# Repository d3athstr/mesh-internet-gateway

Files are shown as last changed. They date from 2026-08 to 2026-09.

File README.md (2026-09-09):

# Mesh Internet Gateway (`meshgw`)

Wired-Ethernet Raspberry Pi + 1 W SX1262 LoRa gateway running **`meshtasticd`**.
Bridges the Empire12 / Techtaria LoRa mesh to the internet over MQTT, and
publishes **E12-owned nodes only** to the public Meshtastic map directories.

PartsBin project **[18]**. Status: **DEPLOYED AND LIVE 2026-09-09.** The HAT is
populated, the Pi is wired and provisioned, and the node is on the mesh with the
MQTT bridge connected.

**The E22 land pattern is VERIFIED.** `meshtasticd` reported `sx1262 init
success` on first start with the module soldered to a rev A board — so the
boards fabbed on the recorded `GEOMETRY_OVERRIDE` are good, and that override is
now cleared in `fab_gate.py`.

**Projected cost ~$81.81**, of which **$35.00 is the Raspberry Pi itself** —
check the shelf first, a spare 3B/3B+/4 makes that line $0. The next largest
is the E22 at **$17.10**, which is what was actually paid on a single-item
AliExpress order; LCSC lists the bare module at ~$7.19, so the difference is
probably bundled shipping and worth checking before buying a second one. The
custom HAT is ~$0.80 ($4 for 5 boards) and the printed enclosure ~$1.20 of
filament — between them under 3 % of the build.

---

## Why this exists

Today the mesh's only internet-adjacent node is the Heltec V4 gateway
`!f66ae684`, a WiFi-attached node on the IoT VLAN. It is a poor
foundation for an internet bridge:

| Problem | Evidence |
|---|---|
| ESP32 **WiFi-hang** — CPU alive, WiFi stack dead, every TCP client drops | Down again **2026-08-10 ~12:37**, ops bridge crash-looping `No route to host` → `BrokenPipe`. Needs a Tuya-switch power cycle to recover. |
| Serves **one** streaming TCP-API client, reliably | Already forced HA onto its own dedicated V3 radio (**D049**) |
| Bridge does **not** auto-reconnect | `meshtastic-bridge-watchdog.timer` exists solely to paper over it |
| WiFi-only | No wired path; it lives on E12-DMZ WiFi |

That radio is on the **load-bearing OOB control path** (4th reach channel,
D048). Hanging an internet/MQTT bridge off it stacks a new dependency on the
component that is already the mesh's most frequent outage.

`meshgw` is a separate, wired, purpose-built box. The V4 keeps doing C&C;
`meshgw` owns the internet bridge.

---

## Design

| Piece | Choice | Why |
|---|---|---|
| Host | **Raspberry Pi 3B/3B+** (wired Ethernet) | Native Ethernet kills the WiFi-hang failure mode. `meshtasticd` is a real Linux daemon — multiple concurrent API clients, no single-TCP-slot contention. Cheapest board with Ethernet + 40-pin header; a spare is likely already on the shelf. |
| Radio | **Ebyte E22-900M30S** (SX1262 + PA, 30 dBm) | ~$14 bare module vs ~$30 for a commercial LoRa HAT, and **1 W / 30 dBm** vs the Heltec's 22 dBm SX1262 ceiling — ~8 dB more link budget on the same mesh. |
| Carrier | **Custom HAT PCB** (`hardware/meshgw-hat/`) | A bare module needs a carrier. KiCad 9 headless, `gen.py` + freerouting — same workflow as the OSL / FD2 / Warden carriers. |
| Enclosure | **3D-printed, parametric** (`enclosure/`) | OpenSCAD source. Indoor shelf/rack box — *not* weatherproof. |
| Uplink | MQTT → `mqtt.meshtastic.org` | What makes nodes appear on the public map directories. |

### Ruled out: ESP32 + Ethernet

WT32-ETH01 (ESP32 + LAN8720) would have been the cheapest wired option
(~$8). **Rejected:** native ESP32 Ethernet support is
[meshtastic/firmware PR #9586](https://github.com/meshtastic/firmware/pull/9586),
which is **closed and never merged** (verified 2026-08-10 via the GitHub API).
Using it means maintaining a firmware fork on the OOB control path. Not
acceptable for this role.

### Ruled out: reuse an in-stock Heltec V4

Zero cost (2 on hand), but it reintroduces the exact WiFi-hang failure mode
that has the current gateway down as this is being written. Reasonable as a
**cold standby**, not as the primary.

---

## Privacy boundary — read `docs/privacy-boundary.md`

This is the part that must not be got wrong.

- **Only E12-owned nodes** are published: `meshgw` itself, the Heltec V4
  gateway, the HA V3, and the e12solar RAK router.
- **Techtaria customer-home endpoints stay dark.** No `ok_to_mqtt`, no map
  reporting, ever. Publishing them would put approximate customer home
  locations on public maps.
- **`paw-cmd` (idx 1, C&C) and `Techtaria` (idx 2, community) have uplink AND
  downlink OFF.** Only the default primary channel uplinks. Downlink on the
  C&C channel would let internet-sourced packets inject into the command path.

The HMAC envelope on the C&C receiver is a second line of defence, not a
reason to relax the first.

---

## Repo layout

```
config/meshtasticd/    config.yaml (E22 pinout), MQTT + channel policy, systemd
hardware/meshgw-hat/   KiCad: netlist.py, gen.py, gen_pcb.py, route.sh,
                       check_geometry.py, lib.pretty/
enclosure/             OpenSCAD parametric case + build notes
docs/                  design notes, privacy boundary, provisioning runbook
scripts/               provisioning helpers
```

`netlist.py` is the **single source of truth for the pinout** — the schematic
generator, the board generator and (by hand) `config/meshtasticd/config.yaml`
all derive from it. It used to be duplicated in `gen.py` and `gen_pcb.py` with
a comment saying the two must mirror each other; on 2026-08-11 they silently
stopped mirroring each other. Change the map in one place.

## The HAT is mechanically verified, the footprints are not

These are two different claims and only the first one is true.

`check_geometry.py` asserts 27 facts about the **routed** board against the
Raspberry Pi HAT mechanical specification and the Pi 3B+: outline 65 x 56 mm
with R3 corners, all 40 header pads on the spec grid from pin 1 at
(8.37, 4.77), four 2.75 mm mounting holes with 6.2 mm isolated lands, no
copper over the Pi 3B+ PoE header, the ground pour actually filled, and the
`+5V` width. It exists because on this toolchain **a board can pass DRC with
0 violations and 0 unconnected and still be scrap** — the previous revision
of this board did exactly that with its two header rows swapped, which would
have put every SPI signal on its neighbour's pin.

Run it on anything you are about to fab. `route.sh` runs it automatically.

Two deliberate deviations from the spec: there are no camera/display flex
cutouts, and there is no ID EEPROM. Without the EEPROM this is a board in the
HAT *form factor*, not a certified HAT, and the Pi will not auto-configure it
— which is fine here, because `meshtasticd` is told the pinout explicitly.

### Pi 3B+ PoE header

The 3B+ adds a 4-pin PoE header (J14) that the 3B does not have, and it stands
tall enough to foul a HAT. The board has an **edge-open notch** rather than an
enclosed cutout, because J14 leaves only ~1 mm to the board edge and an
enclosed cutout would leave a 1 mm FR4 bridge that would snap.

Fit is the smaller reason. J14 sits on the Ethernet magnetics' centre taps, so
on a PoE-capable switch those pins can carry ~48-57 V — and this is by
definition a wired-Ethernet gateway, so it is exactly the machine likely to be
plugged into such a switch. Copper over J14 is checked for, not assumed.

## Build state

| Item | State |
|---|---|
| PartsBin project [18] + BOM | **done** — 11 lines |
| meshtasticd config | **verified on hardware** — SX1262 comes up on the documented pinout |
| Device provisioning script | **run against real hardware 2026-09-09 and fixed** — three defects that aborted it under `set -e` (`position.ok_to_mqtt` is not a field; region/coordinate writes reboot the radio; `mqtt.tls_enabled` is rejected by meshtasticd). Admin key and all channel PSKs come from Vault |
| HAT PCB | **rev A, gerbers built, cleared to order 2026-08-12.** Mechanically verified against the HAT spec and the Pi 3B+ (see below); 119 segments, 0 vias, DRC 0/0, ERC 0, 27/27 mechanical assertions, schematic netlist matches `netlist.py`. Fab package `out/fab/meshgw-hat-revA-gerbers.zip`. **Exported on a recorded override — U1's land pattern still has not met a physical module. CHECK U1'S FIT BEFORE SOLDERING.** See `fab_gate.py` |
| Enclosure | **DRAFT** — all three parts render solid, dimensions not validated against a real Pi + HAT stack. Print `coupon` first |
| Deployment | **LIVE 2026-09-09** — wired primary on `meshgw.empire12.net`, MQTT connected, map reporting on. MQTT is PLAINTEXT: meshtasticd rejects the whole MQTT config when `tls_enabled` is set |

### Bare boards were ordered with U1's land pattern unverified — on purpose

Don's call, 2026-08-12, recorded in `fab_gate.py` rather than laundered into a
flag that claims the unknown was resolved. `GEOMETRY_VERIFIED` is still
`False`; a separate `GEOMETRY_OVERRIDE` string permits the export and says who
decided, when, and why. Six weeks from now "verified" and "we decided to risk
it" are very different things to read.

The reasoning: boards are ~$2 and JLCPCB shipping is $6–25, so batching this
into the same checkout as OSL, FD2, pool and Sentinel costs ~$2 marginal.
Holding it back would pay that shipping charge again later *with certainty*.
If the land pattern is wrong the loss is ~$2 of board plus one respin's
shipping — cheaper in expectation than waiting, unless no further order is
ever placed.

**This is a real risk, not a formality.** The E22 solders to castellated pads,
so a wrong land pattern makes these boards scrap. That is unlike the Sentinel
carrier, where the open items were modules on headers and a wrong guess costs
a module rather than a respin.

**When the module arrives, before any soldering:** offer it up to the bare
board. Check the 2.54 mm pitch, both irregular gaps (7.60 mm pin 19→20,
5.46 mm pin 21→22), and that the castellations land on the 1 mm of pad left
outside the module body. Then set `GEOMETRY_VERIFIED = True` and clear
`GEOMETRY_OVERRIDE`. The board silkscreens the same warning, because that is
the object you will be holding at that moment.

### Still to check before the parts go on

1. **The E22-900M30S land pattern, against the physical module** (above). The
   footprint is internally self-consistent with its cited datasheet figures —
   pad count, first-pad offset, pitch, both irregular gaps and the pin ring
   direction were re-checked 2026-08-12 — but that only proves it was
   transcribed correctly, not that the source figures are right. Note the
   deliberate deviation: the land is 2.0 mm wide against a 0.80 mm
   castellation, centred on the body edge so 1 mm sits outside for a solder
   fillet. That is correct practice; do not "fix" it back to 0.80.
2. **Hand-check power-trace width.** KiCad DRC has no current check. The E22
   pulls ~650 mA peak on a 30 dBm TX burst; `route.sh` asks for 0.4 mm on
   `+5V`, which IPC-2221 puts at ~1.24 A on 1 oz external copper for a 10 °C
   rise — about 1.9x the peak. It is not wider because it cannot be: every
   `+5V` run has to thread the 1.04 mm gaps between the header's pads, and at
   0.5 mm and 1.0 mm freerouting could not finish the board at all. If you
   want more margin, the honest fix is a second `+5V` path on B.Cu, not a
   bigger number in `route.sh`.
3. **Confirm the Pi's 5V rail holds through a TX burst.** The E22 runs from
   **5 V, not 3V3** — the datasheet is explicit that ">=5.0 V ensures output
   power", and its SPI/control pins are 3.3 V logic so they land on the Pi's
   GPIO directly. A sagging rail during TX presents as terrible range, not as
   a power fault, which is why `provision-meshgw.sh` starts at `tx_power 22`
   and leaves 30 for after the rail is proven.
4. Check SMA vs **RP**-SMA on the pigtail against the antennas in stock.
5. **Swap C1 for a 10 V or 16 V part.** The 1000 µF in stock is rated 6.3 V;
   on a 5 V rail that is ~26 % headroom, right at the usual 80 % derating
   limit, and the Pi's 5 V rail does not sit low. The C1 footprint
   (D8.0 mm, P3.50 mm) takes either.
6. **Print the enclosure `coupon`** and offer it up to a real Pi 3B before
   committing to the ~4 h full base print.

> **Never power the E22 without an antenna attached.** 1 W into an open
> circuit damages the PA.

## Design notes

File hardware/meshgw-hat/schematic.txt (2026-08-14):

# MeshGW Pi HAT - E22-900M30S carrier - text schematic
# rev A
# source: meshgw-hat.kicad_sch
# generated 2026-08-14 by kicad_text_schematic.py - DO NOT HAND-EDIT ABOVE THE HAND NOTES MARKER
# regenerate: kicad_text_schematic.py /root/mesh-internet-gateway/hardware/meshgw-hat/meshgw-hat.kicad_sch
#
# Refdes below match the drafted schematic and the PCB exactly.

PARTS (5)
  C1     1000uF 6.3V                  
  C2     0.1uF                        
  C3     0.1uF                        
  J1     RPi 40-pin GPIO              
  U1     E22-900M30S                  

NETS (12)
  NET /GND
      C1.2(-) C2.2(2) C3.2(2) J1.14(GND) J1.20(GND) J1.25(GND)
      J1.30(GND) J1.34(GND) J1.39(GND) J1.6(GND) J1.9(GND) U1.1(GND)
      U1.11(GND) U1.12(GND) U1.2(GND) U1.20(GND) U1.22(GND) U1.3(GND)
      U1.4(GND) U1.5(GND)
  NET /+3V3          J1.1(3V3) J1.17(3V3)
  NET /+5V           C1.1(+) C2.1(1) C3.1(1) J1.2(5V) J1.4(5V) U1.10(VCC) U1.9(VCC)
  NET /BUSY          J1.13(GPIO27) U1.14(BUSY)
  NET /DIO1          J1.11(GPIO17) U1.13(DIO1)
  NET /MISO          J1.21(GPIO9_MISO) U1.16(MISO)
  NET /MOSI          J1.19(GPIO10_MOSI) U1.17(MOSI)
  NET /NRST          J1.15(GPIO22) U1.15(NRST)
  NET /NSS           J1.29(GPIO5) U1.19(NSS)
  NET /RXEN          J1.31(GPIO6) U1.6(RXEN)
  NET /SCK           J1.23(GPIO11_SCLK) U1.18(SCK)
  NET /TXEN          J1.33(GPIO13) U1.7(TXEN)

UNCONNECTED PINS (2) - free for future use
  U1.21(ANT) U1.8(DIO2)

POLARITY / ORIENTATION - the class of error that passes DRC
  C1     check polarity if electrolytic/tantalum
  C2     check polarity if electrolytic/tantalum
  C3     check polarity if electrolytic/tantalum

# ---- HAND NOTES (preserved on regeneration) ----
# ASCII power-path diagram, divider ratios, anything the netlist
# reads poorly. This section survives regeneration.

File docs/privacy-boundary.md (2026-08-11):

# Privacy boundary

Decided 2026-08-10 (Don). This document is the authority; if code or config
disagrees with it, the code is wrong.

## The rule

> **Only Empire12-owned nodes are published to the internet.
> Techtaria customer-home endpoints are never published.**

Publishing a node to `mqtt.meshtastic.org` puts it on the public map
directories ([meshmap.net](https://meshmap.net/),
[meshtastic.liamcottle.net](https://meshtastic.liamcottle.net/)) along with
an approximate position. Default map-report position precision is a ~1459 m
deviation — that is *neighbourhood* resolution, which is more than enough to
identify which subdivision a customer lives in, and it is paired with a
stable node ID and a long name.

Techtaria endpoints sit inside customers' houses. Their position is customer
PII that we hold in order to run their home automation, not ours to
broadcast. There is no product benefit that justifies it.

## Published (E12-owned, opt in)

| Node | ID | Notes |
|---|---|---|
| `meshgw` | TBD | this gateway |
| Heltec V4 gateway | `!f66ae684` | E12-DMZ, HQ |
| HA V3 | `!3368d390` | serial-attached to HA |
| e12solar RAK router | `!918e5b5a` | outdoor solar ROUTER |

All four sit at the Empire12 home site — a location that is already the
public origin of this mesh, and Don's own property.

## Not published (dark)

- **Every Techtaria customer endpoint**, including the bench prototype
  `!f66b6bc0`. Even though the prototype is currently on-site, keeping the
  whole `pawmations-*` endpoint class dark means the fleet default is safe:
  a node that gets deployed to a customer never has to be *remembered* to be
  turned off.

Per-node settings that must stay off on endpoints:

```
mqtt.enabled                 = false
mqtt.map_reporting_enabled   = false
mqtt.proxy_to_client_enabled = false
position.ok_to_mqtt          = false   # "OK to MQTT" / share-position flag
```

## Channel policy on `meshgw`

| Idx | Channel | Uplink | Downlink | Why |
|---|---|---|---|---|
| 0 | primary (default LongFast) | **yes** | no | This is the only channel that reaches the public broker. Carries public mesh traffic only. |
| 1 | `paw-cmd` | **NO** | **NO** | C&C. Uplink would relay command traffic to a public broker; **downlink would let internet-sourced packets inject into the command path.** |
| 2 | `Techtaria` | **NO** | **NO** | Customer community chat. Private to the fleet; already relayed cloud-side by the ops bridge into DDB `pawmations-vega-mesh`. |

Downlink-off on idx 1 is the important one. The C&C receiver does validate an
HMAC envelope with a nonce-replay store, but that is defence in depth — it is
not a licence to accept packets from the open internet.

## Things that leak by accident

- **`mqtt.proxy_to_client_enabled`** routes MQTT through a connected client
  instead of the device's own network stack. It bypasses the assumption that
  "the endpoint has no internet, so it cannot publish". Keep it false fleet-wide.
- **Map reports are unencrypted by design** — that is how public maps read
  them. Enabling map reporting on a node with a precise fixed position
  publishes that position regardless of channel PSKs.
- **`position.fixed_position` + real coordinates** on an endpoint is exactly
  the data we do not want uplinked. Endpoints legitimately have fixed
  positions for local use; the protection is `ok_to_mqtt=false`, not the
  absence of coordinates.
- A future fleet-wide `--set` batch is the most likely way this rule gets
  broken. Any bulk Meshtastic config change must be `--limit`-style scoped to
  E12 nodes, never applied to `all`.

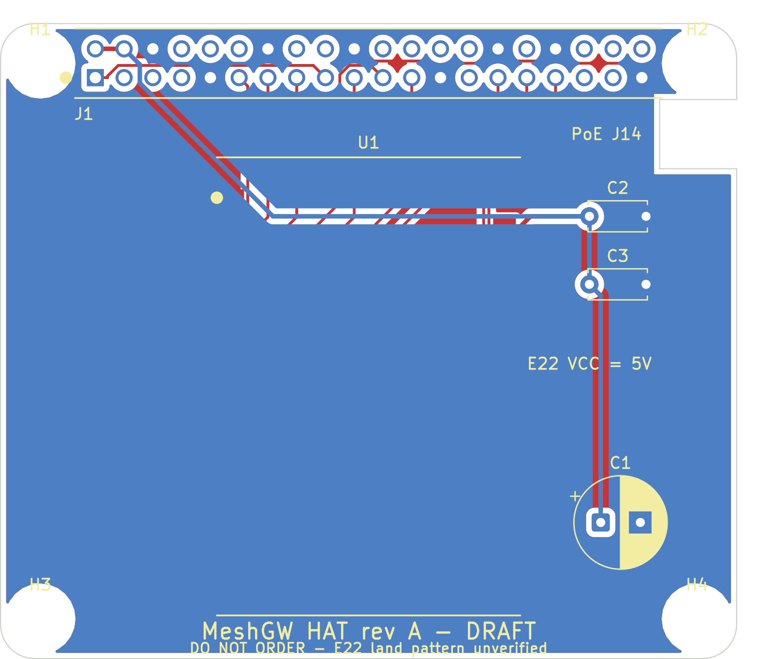
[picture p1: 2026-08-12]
hardware/meshgw-hat/out/pcb-routed.png

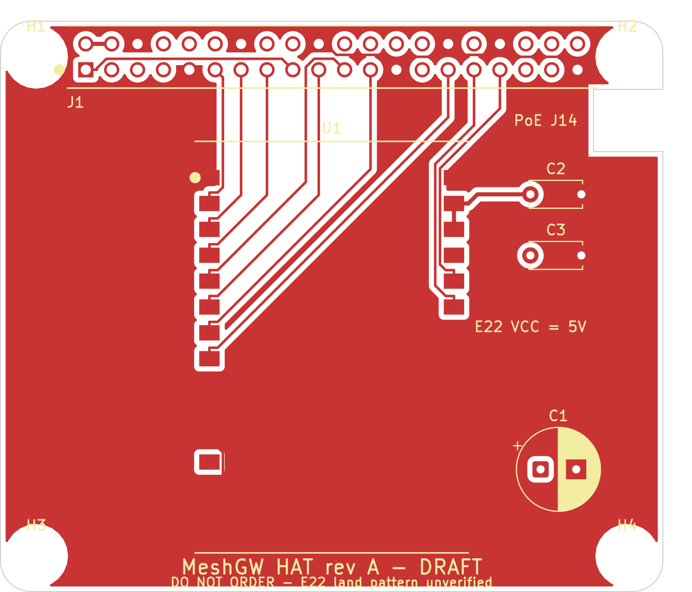
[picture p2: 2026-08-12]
hardware/meshgw-hat/out/f-cu.png

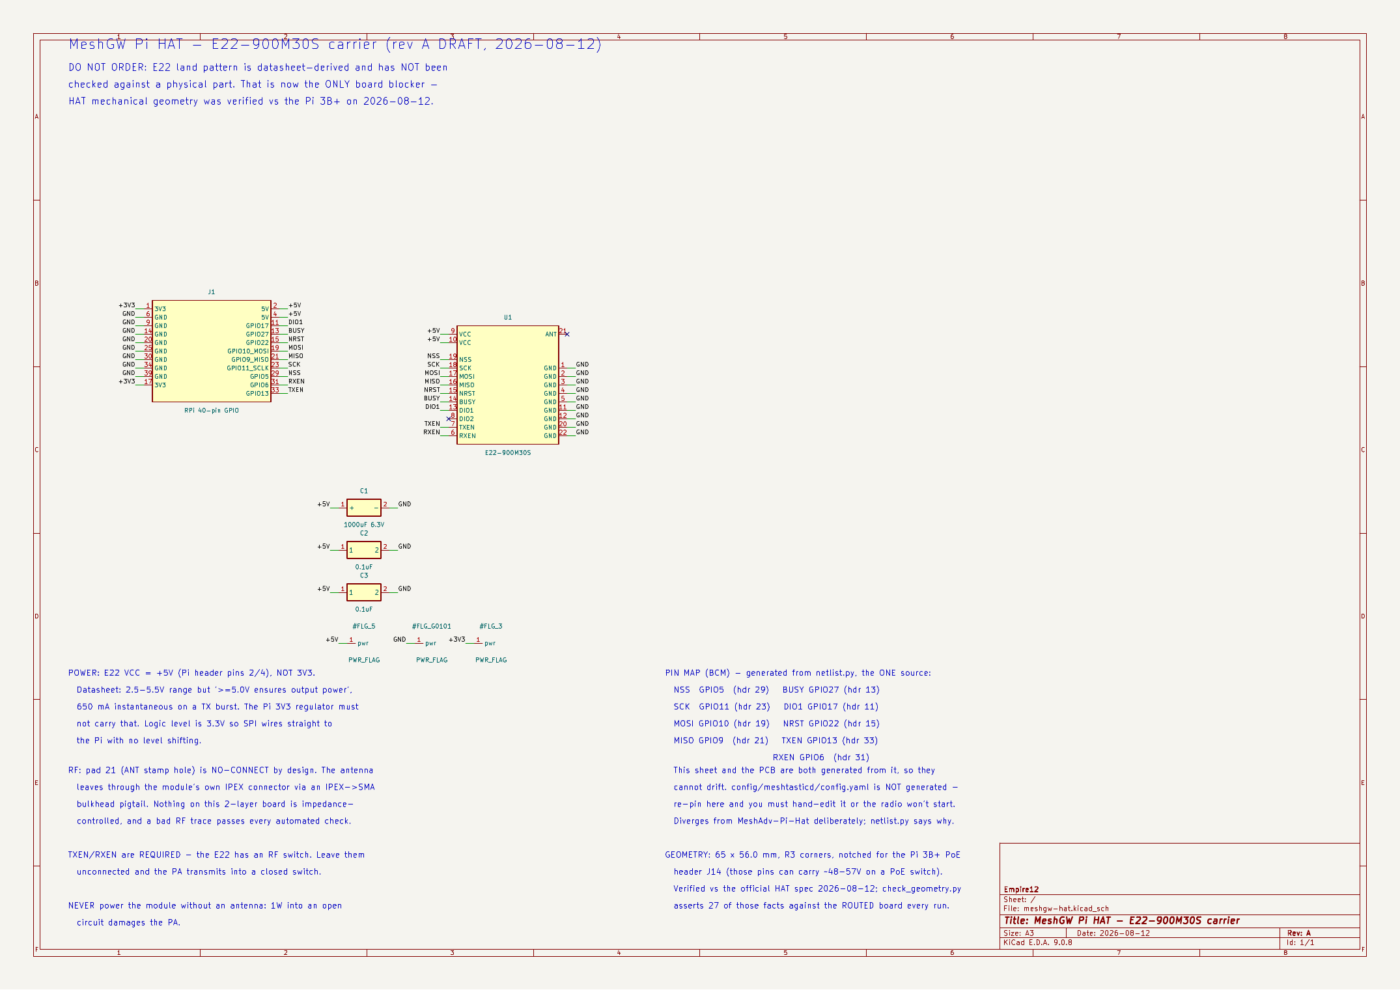
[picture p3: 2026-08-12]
hardware/meshgw-hat/out/sch-1.png

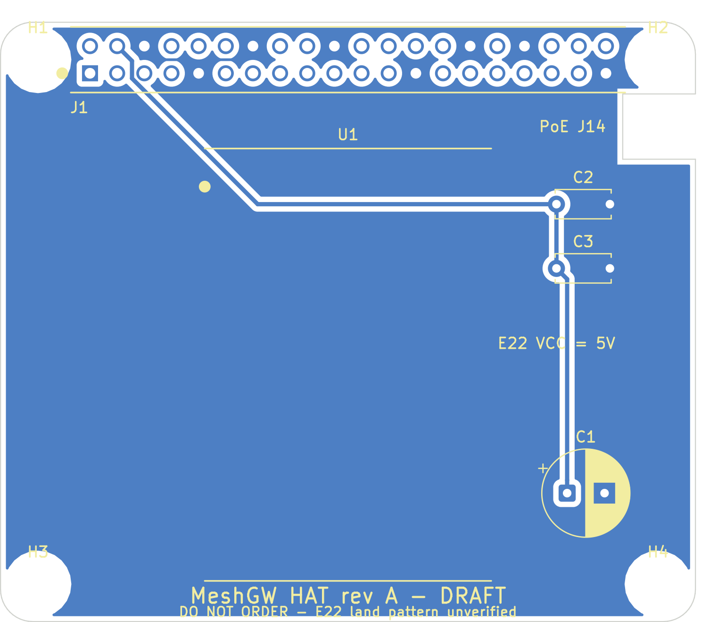
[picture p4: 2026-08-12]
hardware/meshgw-hat/out/b-cu.png

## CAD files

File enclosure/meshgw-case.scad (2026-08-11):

// MeshGW enclosure — Raspberry Pi 3B/3B+ with the MeshGW HAT stacked.
//
//   openscad -D part=\"base\" -o meshgw-base.stl meshgw-case.scad
//   openscad -D part=\"lid\"  -o meshgw-lid.stl  meshgw-case.scad
//   openscad -D part=\"all\"  meshgw-case.scad          // preview both
//
// INDOOR ONLY. This is a shelf/rack box: vented, not sealed, no gasket. The
// outdoor RF node on this mesh is the e12solar RAK4631 in its LeMotech IP65
// enclosure — do not repurpose this design for outdoor use.
//
// DIMENSIONS ARE NOMINAL AND UNVERIFIED against a physical Pi. Print the
// test coupon (part="coupon") FIRST — it is just the mounting-boss pattern
// and the port wall, ~10 minutes of filament — and offer it up to the actual
// Pi before committing to a 4-hour full print. Port positions in particular
// vary between Pi models.

part = "all";           // "base" | "lid" | "coupon" | "all"
$fn = 48;

/* ---------------------------------------------------------------- Pi */
pi_l        = 85.0;     // Pi 3B/3B+ board length
pi_w        = 56.0;     // board width
pi_t        = 1.4;      // board thickness
pi_hole_dx  = 58.0;     // mounting hole spacing, long axis
pi_hole_dy  = 49.0;     // mounting hole spacing, short axis
pi_hole_in  = 3.5;      // hole inset from the board corner
pi_hole_d   = 2.75;     // hole diameter (M2.5 clearance)

/* -------------------------------------------------------------- stack */
// Pi board -> standoff -> HAT board -> E22 module -> headroom.
standoff_h  = 11.0;     // Pi top face to HAT underside (stacking header)
hat_t       = 1.6;      // HAT board thickness
e22_t       = 3.6;      // E22-900M30S body height (datasheet: 3.6 mm)
head_room   = 10.0;     // clearance above the E22 for the IPEX pigtail, which
                        // bends sideways off the module and does not like a
                        // tight radius. 10 rather than 6 also buys the band of
                        // wall the exhaust vents need: they have to sit above
                        // the tallest connector opening (USB, top at ~23.8)
                        // and below the lid lip, and at head_room = 6 there
                        // was no gap left between the two.

/* ------------------------------------------------------------ shell */
wall        = 2.4;      // 3 perimeters at 0.4 mm nozzle, 0.2 mm layers
floor_t     = 2.4;
boss_h      = 4.0;      // Pi underside to floor: clears solder + microSD lip
clear       = 1.0;      // gap between board edge and inner wall, per side
lip_h       = 3.0;      // lid register lip
lip_gap     = 0.25;     // lid-to-base clearance; loosen to 0.35 if it binds

inner_l = pi_l + 2*clear;
inner_w = pi_w + 2*clear;
inner_h = boss_h + pi_t + standoff_h + hat_t + e22_t + head_room;

out_l = inner_l + 2*wall;
out_w = inner_w + 2*wall;

/* -------------------------------------------------------------- ports */
// Measured from the Pi board's origin corner (the microSD end, port side).
// [name, centre along that wall, opening width, opening height, sill height
//  above the Pi's TOP face]. VERIFY THESE AGAINST A REAL BOARD.
//
// Long wall (+Y, where Ethernet and USB live):
eth_x = 10.25;  eth_w = 16.0;  eth_h = 14.0;
usb1_x = 29.0;  usb_w = 14.5;  usb_h = 16.0;
usb2_x = 47.0;
// Short/bottom wall (-Y edge): micro-USB power, HDMI, audio.
pwr_x  = 10.6;  pwr_w  = 11.0;  pwr_h = 6.0;
hdmi_x = 32.0;  hdmi_w = 16.0;  hdmi_h = 8.0;
aud_x  = 53.5;  aud_w  = 10.0;  aud_h = 8.0;
// SMA bulkhead for the antenna pigtail: on the -X end wall, above the HAT so
// the connector body clears the board edge. 6.5 mm is the usual SMA bulkhead
// thread clearance. The centre is set from the HAT's top face rather than
// from the floor so it tracks standoff_h if that changes.
sma_d  = 6.5;
sma_z  = boss_h + pi_t + standoff_h + hat_t + 6.0;

module port(cx, cz, w, h) {
    // cx = centre along the wall, cz = centre height above the floor inside
    translate([cx, 0, cz]) cube([w, wall*4, h], center = true);
}

module boss(x, y, h, od = 6.0) {
    translate([x, y, 0]) difference() {
        cylinder(d = od, h = h);
        translate([0, 0, 1.2]) cylinder(d = 2.2, h = h);   // M2.5 self-tap
    }
}

module bosses(h) {
    ox = clear + pi_hole_in;
    oy = clear + pi_hole_in;
    for (x = [ox, ox + pi_hole_dx], y = [oy, oy + pi_hole_dy])
        boss(x, y, h);
}

// Passive convection only. The E22 dumps ~3 W as heat on a sustained TX burst
// and the Pi adds its own; a sealed box would cook both.
//
// Intake is LOW on the +X end wall (under the Pi board) and exhaust is HIGH on
// both long walls, so air crosses the whole stack instead of pooling. The
// first version put tall slots low on the long walls and they cut straight
// through the Ethernet, USB, HDMI and audio openings — the slots and the ports
// merged into one ragged hole. Anything on a long wall now lives in the band
// above the connectors, which is why these z values are derived rather than
// typed in: connector_top < vent < lid lip.
connector_top = floor_t + boss_h + pi_t + max(eth_h, usb_h);
lip_bottom    = floor_t + inner_h - lip_h;
vent_h        = 3.5;
vent_z        = (connector_top + lip_bottom) / 2;   // centred in the free band

module vents_high() {
    // one wall's worth of exhaust, cut at y = 0 (the -Y wall)
    for (i = [0 : 6])
        translate([12 + i*10, -wall*2, vent_z - vent_h/2])
            cube([5, wall*4, vent_h]);
}

module vents_intake() {
    // +X end wall, below the Pi board so cool air enters under it
    for (i = [0 : 3])
        translate([inner_l - wall, 8 + i*12, floor_t + 1.0])
            cube([wall*4, 5, boss_h - 1.5]);
}

module base() {
    difference() {
        union() {
            // shell
            difference() {
                translate([-wall, -wall, 0])
                    cube([out_l, out_w, floor_t + inner_h]);
                translate([0, 0, floor_t])
                    cube([inner_l, inner_w, inner_h + 1]);
            }
            bosses(floor_t + boss_h);
        }
        // --- ports on the +Y long wall ---
        translate([0, inner_w + wall, 0]) {
            port(eth_x + clear,  floor_t + boss_h + pi_t + eth_h/2,  eth_w, eth_h);
            port(usb1_x + clear, floor_t + boss_h + pi_t + usb_h/2,  usb_w, usb_h);
            port(usb2_x + clear, floor_t + boss_h + pi_t + usb_h/2,  usb_w, usb_h);
        }
        // --- ports on the -Y wall ---
        port(pwr_x + clear,  floor_t + boss_h + pi_t + pwr_h/2,  pwr_w, pwr_h);
        port(hdmi_x + clear, floor_t + boss_h + pi_t + hdmi_h/2, hdmi_w, hdmi_h);
        port(aud_x + clear,  floor_t + boss_h + pi_t + aud_h/2,  aud_w, aud_h);
        // --- SMA bulkhead on the -X end wall ---
        translate([-wall*2, inner_w/2, sma_z])
            rotate([0, 90, 0]) cylinder(d = sma_d, h = wall*4);
        // --- microSD slot on the -X end wall, at board level ---
        translate([-wall*2, inner_w/2 - 8, floor_t + boss_h - 1.5])
            cube([wall*4, 16, 3.5]);
        vents_high();
        translate([0, inner_w, 0]) mirror([0, 1, 0]) vents_high();
        vents_intake();
    }
}

module lid() {
    difference() {
        union() {
            translate([-wall, -wall, 0]) cube([out_l, out_w, wall]);
            // register lip, inset by the fit clearance
            translate([lip_gap, lip_gap, -lip_h])
                difference() {
                    cube([inner_l - 2*lip_gap, inner_w - 2*lip_gap, lip_h]);
                    translate([wall, wall, -1])
                        cube([inner_l - 2*wall - 2*lip_gap,
                              inner_w - 2*wall - 2*lip_gap, lip_h + 2]);
                }
        }
        // lid vents, offset from the base vents so they do not line up and
        // let dust fall straight through onto the board
        for (i = [0 : 4])
            translate([24 + i*10, inner_w/2 - 12, -1])
                cube([4, 24, wall + 2]);
    }
}

// Print this first. All four bosses + the -Y port wall: proves hole spacing
// in BOTH axes, boss height and port alignment against a real Pi for ~20 min
// of filament instead of a 4-hour full print.
//
// The floor is a perimeter frame, not a slab — the middle is cut away to save
// filament. The frame must stay wide enough to actually reach all four
// bosses; a narrow strip along one edge leaves the far pair floating in
// space, which slices into two loose pucks (found the hard way: OpenSCAD
// reported 4 volumes).
coupon_frame = 12.0;    // frame width; must exceed pi_hole_in + boss radius
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

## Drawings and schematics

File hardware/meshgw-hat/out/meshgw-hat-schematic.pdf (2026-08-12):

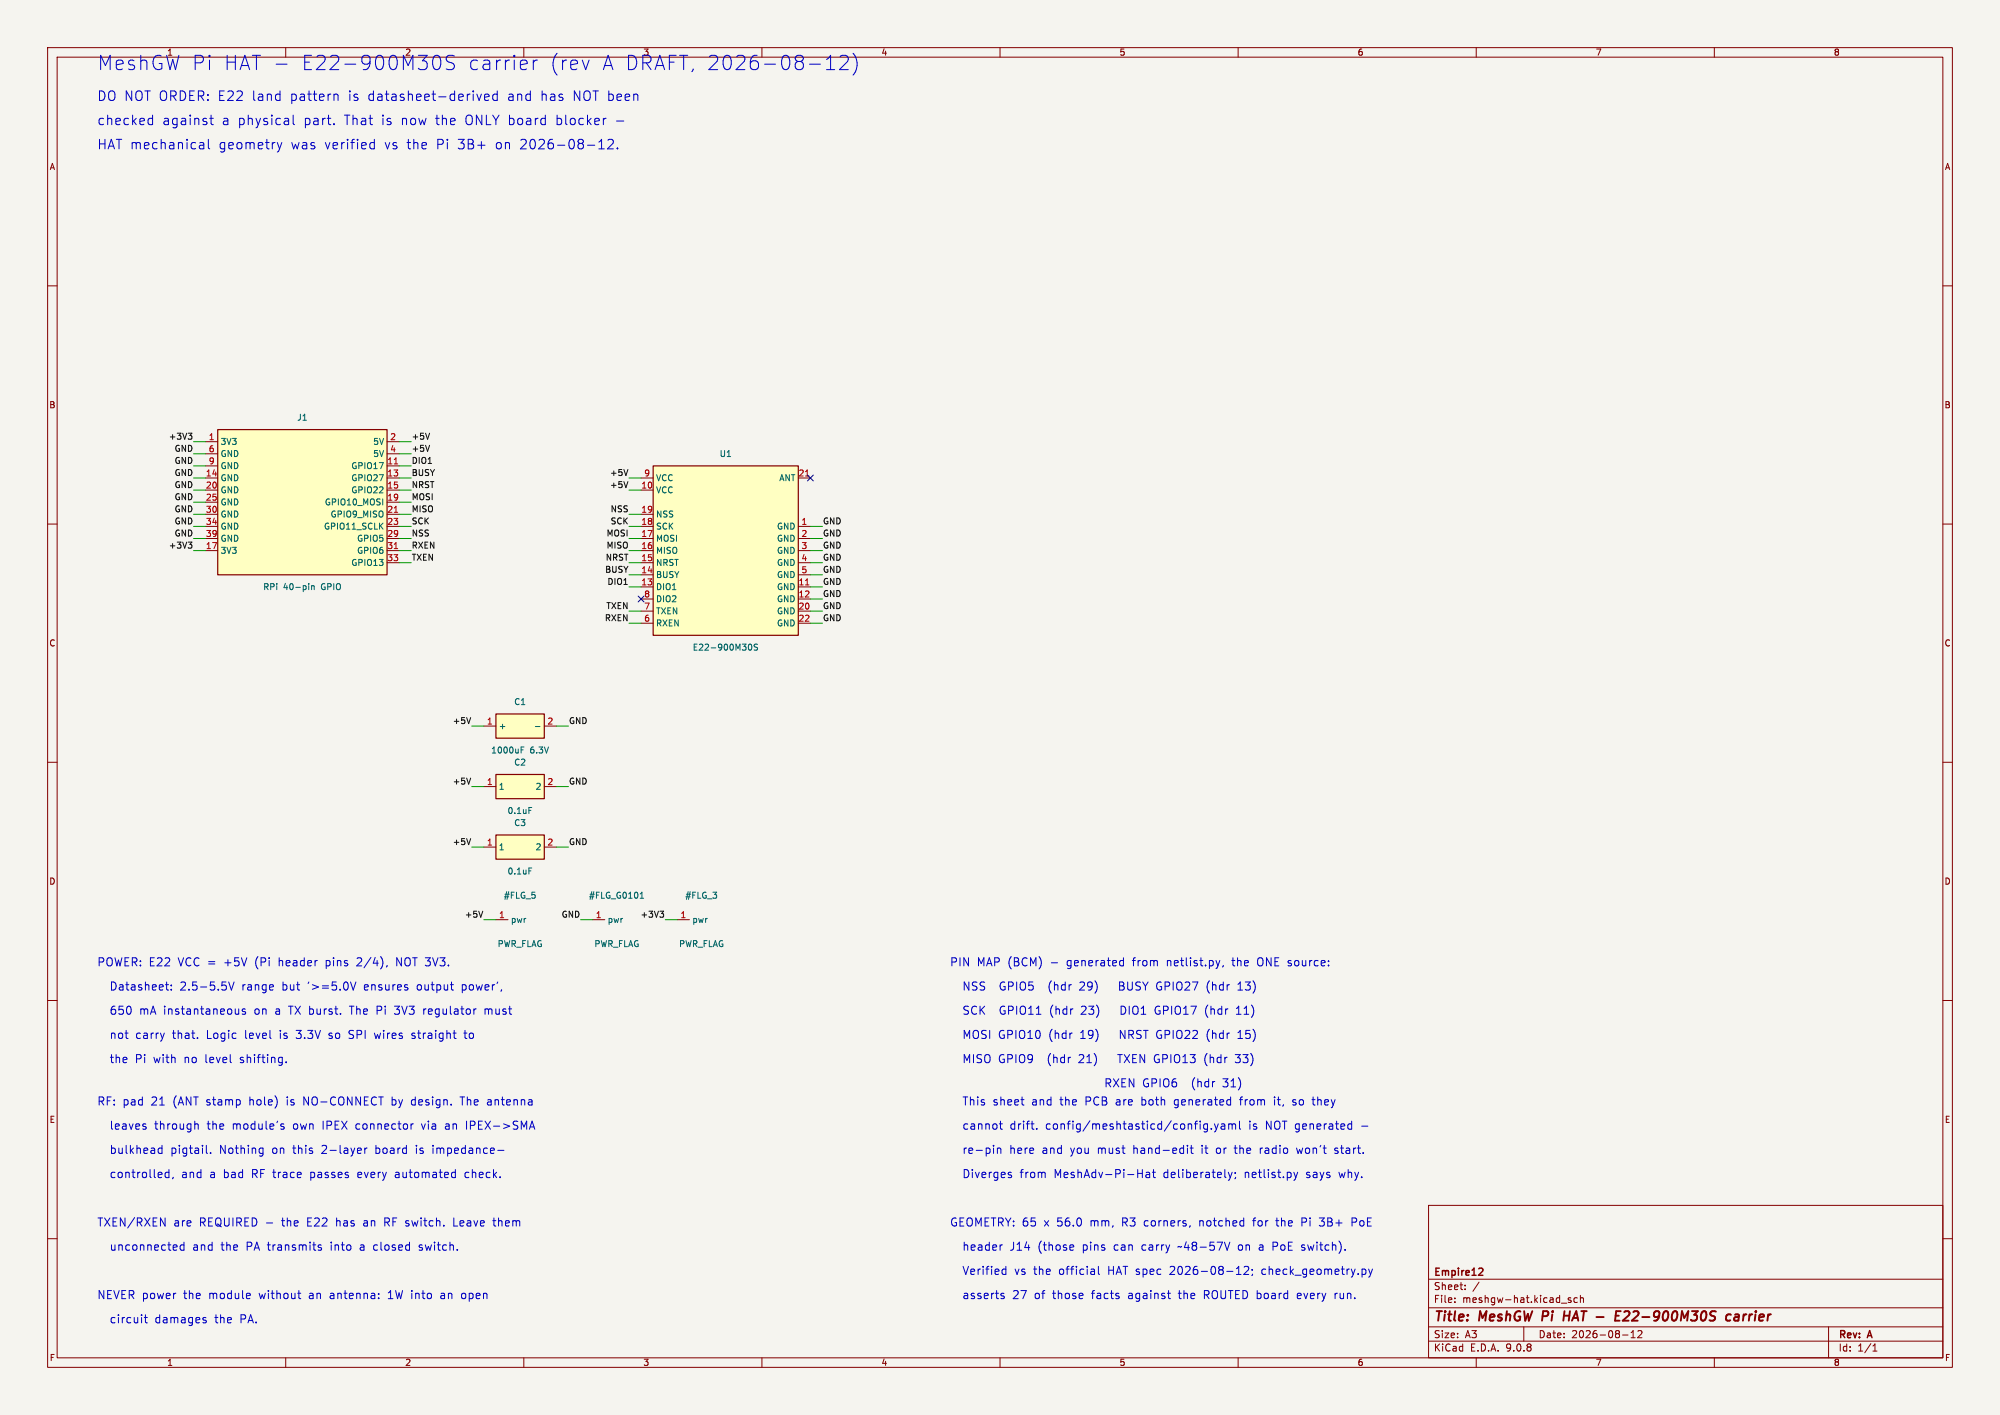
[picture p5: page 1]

checked against a physical part. That is now the ONLY board blocker -

+3V3 GND GND GND GND
GND GND GND

the Pi with no level shifting.

asserts 27 of those facts against the ROUTED board every run. RXEN GPIO6 (hdr 31)
This sheet and the PCB are both generated from it, so they

RF: pad 21 (ANT stamp hole) is NO-CONNECT by design. The antenna

TXEN/RXEN are REQUIRED - the E22 has an RF switch. Leave them

GEOMETRY: 65 x 56.0 mm, R3 corners, notched for the Pi 3B+ PoE

NEVER power the module without an antenna: 1W into an open

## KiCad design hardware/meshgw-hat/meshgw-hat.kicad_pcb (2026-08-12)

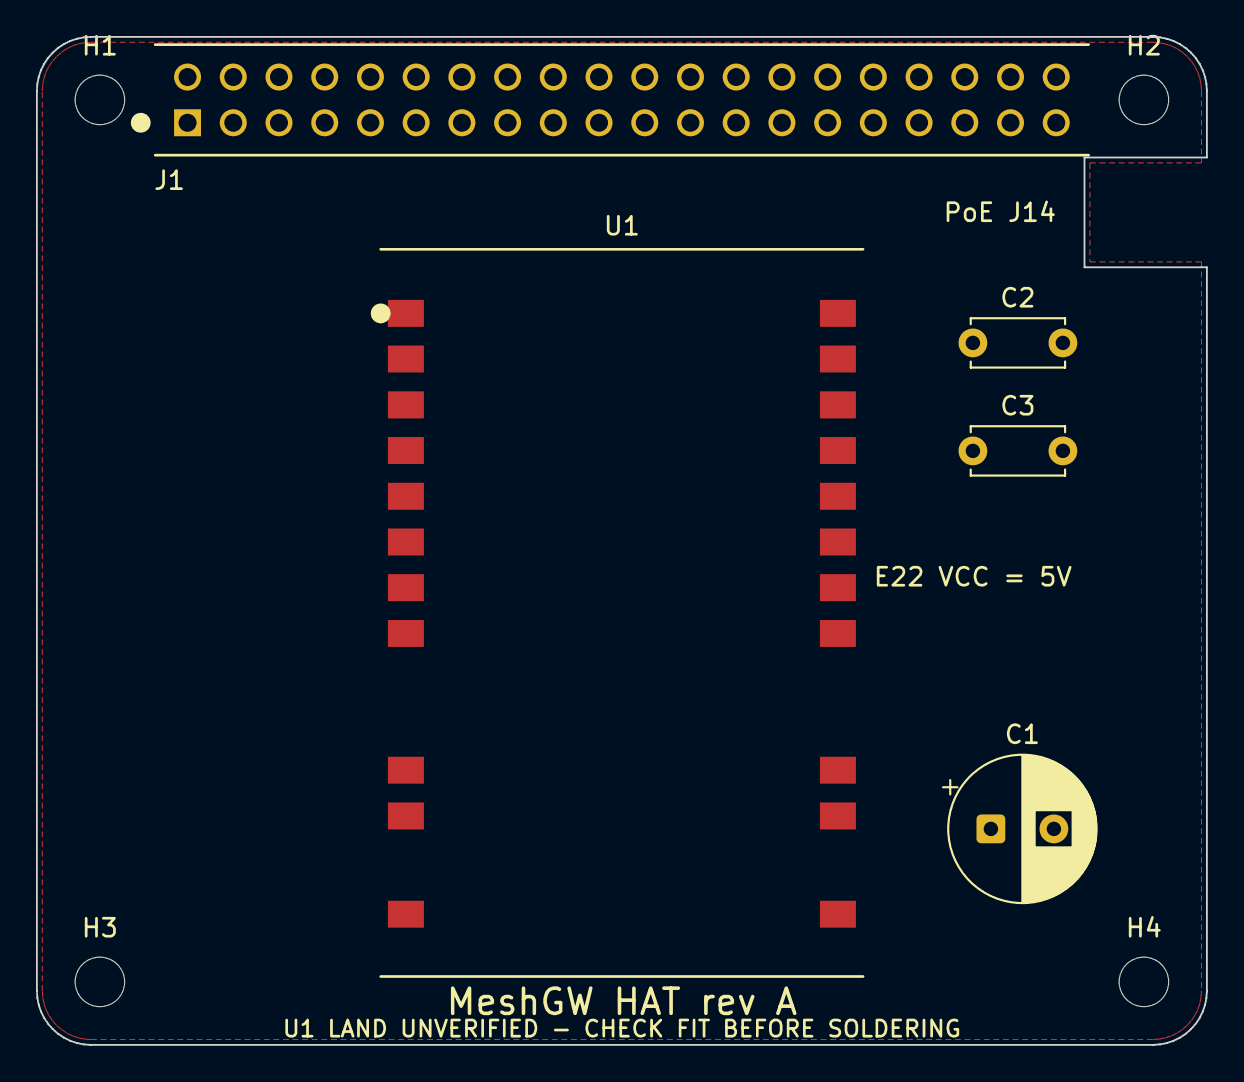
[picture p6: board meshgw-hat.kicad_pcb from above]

Board: 2 copper layers, 65.0 x 56.0 mm, 9 parts (0 on the bottom side), 12 nets, no tracks yet.

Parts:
C1: CP_Radial_D8.0mm_P3.50mm
C2, C3: C_Disc_D5.0mm_W2.5mm_P5.00mm
H1, H2, H3, H4: MountingHole_2.75mm
J1: RPi_GPIO40; RPi_GPIO40_Horizontal
U1: E22-900M30S; E22_900M30S

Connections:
+3V3: J1.1, J1.17
+5V: C1.1, C2.1, C3.1, J1.2, J1.4, U1.9, U1.10
BUSY: J1.13, U1.14
DIO1: J1.11, U1.13
GND: C1.2, C2.2, C3.2, J1.6, J1.9, J1.14, J1.20, J1.25, J1.30, J1.34, J1.39, U1.1, U1.2, U1.3, U1.4, U1.5, U1.11, U1.12, U1.20, U1.22
MISO: J1.21, U1.16
MOSI: J1.19, U1.17
NRST: J1.15, U1.15
NSS: J1.29, U1.19
RXEN: J1.31, U1.6
SCK: J1.23, U1.18
TXEN: J1.33, U1.7

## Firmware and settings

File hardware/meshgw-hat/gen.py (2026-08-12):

#!/usr/bin/env python3
"""Generate the MeshGW Pi HAT symbol library + schematic.

The MeshGW HAT carries an Ebyte E22-900M30S (SX1262 + PA, 1 W) on a Raspberry
Pi 3B/3B+, turning it into a wired-Ethernet Meshtastic gateway running
meshtasticd. Design doc: ../../README.md, privacy rules:
../../docs/privacy-boundary.md.

GEOMETRY AND PINOUT ARE FROM THE DATASHEET, NOT FROM MEMORY
  E22-900M30S User Manual v1.20, sections 2.2 and 3:
    * body 38.5 x 24 x 3.6 mm, 22 castellated pads, 2.54 mm pitch
    * operating voltage 2.5-5.5 V, TYP 5.0 V, ">=5.0V ensures output power"
    * communication level 3.3 V
    * TX current 650 mA instantaneous, RX 14 mA
    * max TX power 30 dBm (29.5 min / 31 max)
    * pin 1-5 GND, 6 RXEN, 7 TXEN, 8 DIO2, 9 VCC, 10 VCC, 11-12 GND,
      13 DIO1, 14 BUSY, 15 NRST, 16 MISO, 17 MOSI, 18 SCK, 19 NSS,
      20 GND, 21 ANT, 22 GND

TWO CONSEQUENCES OF THAT DATASHEET READ, BOTH LOAD-BEARING:

1. VCC IS THE 5 V RAIL, NOT 3V3. The module is rated 2.5-5.5 V but only
   makes rated power at >=5 V, and it pulls 650 mA on a TX burst. The Pi's
   3V3 regulator has no business supplying that; the 5 V rail (straight off
   the USB input) does. Logic stays 3.3 V, so SPI wires to the Pi directly
   with no level shifting. Powering this module from 3V3 would "work" and
   quietly cost most of the 8 dB that motivated choosing it.

2. NO RF IS ROUTED ON THIS BOARD. The module carries its own IPEX connector;
   the antenna leaves via an IPEX->SMA bulkhead pigtail to the enclosure
   wall. Pad 21 (ANT stamp hole) is deliberately LEFT UNCONNECTED. A 2-layer
   autorouted board cannot hold a 50 ohm impedance, and a botched RF trace is
   invisible to every automated check we run.

TXEN/RXEN are driven explicitly from Pi GPIOs (matching the meshtasticd
config and the MeshAdv-Pi-Hat reference) rather than tying TXEN to DIO2. The
datasheet allows the DIO2 shortcut; explicit control is what meshtasticd's
config expects, and it keeps the failure mode diagnosable.

STATUS: rev A, bare boards ordered 2026-08-12 with U1's land pattern still
unverified against a physical module — a deliberate, recorded decision, see
fab_gate.py. CHECK U1's FIT BEFORE SOLDERING IT DOWN.
"""
import json, os, re, uuid

from netlist import NETS, NC, pins   # one netlist, shared with gen_pcb.py

os.chdir(os.path.dirname(os.path.abspath(__file__)))
GRID = 1.27
LIB = "mgw"
PROJ = "meshgw-hat"


def snap(v):
    return round(round(v / GRID) * GRID, 4)


def U():
    return str(uuid.uuid4())


SYMS = {}


def sym(name, ref, fp, pins, w=10.16, datasheet="", desc="", power=False):
    ys = [p[4] for p in pins]
    top, bot = max(ys) + 2.54, min(ys) - 2.54
    body = ""
    if not power:
        body = (f'      (rectangle (start {-w} {top}) (end {w} {bot})\n'
                '        (stroke (width 0.254) (type default))'
                ' (fill (type background)))')
    pl, coords = [], {}
    for num, pn, et, side, y in pins:
        x, rot = (-w - 2.54, 0) if side == "L" else (w + 2.54, 180)
        coords[num] = (x, y)
        pl.append(f'''      (pin {et} line (at {x} {y} {rot}) (length 2.54)
        (name "{pn}" (effects (font (size 1.27 1.27))))
        (number "{num}" (effects (font (size 1.27 1.27)))))''')
    SYMS[name] = coords
    pwr = '    (power)\n' if power else ''
    return f'''  (symbol "{name}"
{pwr}    (pin_names (offset 0.508)) (exclude_from_sim no) (in_bom {"no" if power else "yes"}) (on_board yes)
    (property "Reference" "{ref}" (at 0 {top + 2.54} 0)
      (effects (font (size 1.27 1.27))))
    (property "Value" "{name}" (at 0 {bot - 2.54} 0)
      (effects (font (size 1.27 1.27))))
    (property "Footprint" "{fp}" (at 0 0 0)
      (effects (font (size 1.27 1.27)) (hide yes)))
    (property "Datasheet" "{datasheet}" (at 0 0 0)
      (effects (font (size 1.27 1.27)) (hide yes)))
    (property "Description" "{desc}" (at 0 0 0)
      (effects (font (size 1.27 1.27)) (hide yes)))
    (symbol "{name}_0_1"
{body}
    )
    (symbol "{name}_1_1"
{chr(10).join(pl)}
    )
  )'''


out = []

# ---- E22-900M30S. Pin order below matches the datasheet table exactly. ----
out.append(sym("E22_900M30S", "U", f"{LIB}:E22_900M30S", [
    ("9",  "VCC",  "power_in",     "L",  17.78),
    ("10", "VCC",  "power_in",     "L",  15.24),
    ("19", "NSS",  "input",        "L",  10.16),
    ("18", "SCK",  "input",        "L",   7.62),
    ("17", "MOSI", "input",        "L",   5.08),
    ("16", "MISO", "output",       "L",   2.54),
    ("15", "NRST", "input",        "L",   0.0),
    ("14", "BUSY", "output",       "L",  -2.54),
    ("13", "DIO1", "bidirectional", "L", -5.08),
    ("8",  "DIO2", "bidirectional", "L", -7.62),
    ("7",  "TXEN", "input",        "L", -10.16),
    ("6",  "RXEN", "input",        "L", -12.7),
    ("21", "ANT",  "passive",      "R",  17.78),
    ("1",  "GND",  "power_in",     "R",   7.62),
    ("2",  "GND",  "power_in",     "R",   5.08),
    ("3",  "GND",  "power_in",     "R",   2.54),
    ("4",  "GND",  "power_in",     "R",   0.0),
    ("5",  "GND",  "power_in",     "R",  -2.54),
    ("11", "GND",  "power_in",     "R",  -5.08),
    ("12", "GND",  "power_in",     "R",  -7.62),
    ("20", "GND",  "power_in",     "R", -10.16),
    ("22", "GND",  "power_in",     "R", -12.7)], 15.24,
    "https://www.cdebyte.com/products/E22-900M30S",
    "Ebyte E22-900M30S SX1262+PA 1W LoRa module (VCC=5V, logic 3.3V)"))

# ---- Raspberry Pi 40-pin GPIO header. Numbers are HEADER pin numbers. ----
_pi = [
    ("1",  "3V3",        "L",  25.4), ("2",  "5V",         "R",  25.4),
    ("6",  "GND",        "L",  22.86), ("4", "5V",         "R",  22.86),
    ("9",  "GND",        "L",  20.32), ("11", "GPIO17",    "R",  20.32),
    ("14", "GND",        "L",  17.78), ("13", "GPIO27",    "R",  17.78),
    ("20", "GND",        "L",  15.24), ("15", "GPIO22",    "R",  15.24),
    ("25", "GND",        "L",  12.7),  ("19", "GPIO10_MOSI", "R", 12.7),
    ("30", "GND",        "L",  10.16), ("21", "GPIO9_MISO", "R",  10.16),
    ("34", "GND",        "L",   7.62), ("23", "GPIO11_SCLK", "R",  7.62),
    ("39", "GND",        "L",   5.08), ("29", "GPIO5",     "R",   5.08),
    ("17", "3V3",        "L",   2.54), ("31", "GPIO6",     "R",   2.54),
    ("33", "GPIO13",     "R",   0.0),
]
out.append(sym("RPi_GPIO40", "J", "Connector_PinHeader_2.54mm:PinHeader_2x20_P2.54mm_Vertical",
               [(n, nm, "passive", s, y) for n, nm, s, y in _pi], 17.78,
               "https://pinout.xyz/", "Raspberry Pi 40-pin GPIO header (HAT side)"))

out.append(sym("CP", "C", "Capacitor_THT:CP_Radial_D8.0mm_P3.50mm",
               [("1", "+", "passive", "L", 0.0), ("2", "-", "passive", "R", 0.0)],
               5.08, "", "Polarized electrolytic capacitor"))
out.append(sym("C", "C", "Capacitor_THT:C_Disc_D5.0mm_W2.5mm_P5.00mm",
               [("1", "1", "passive", "L", 0.0), ("2", "2", "passive", "R", 0.0)],
               5.08, "", "Ceramic disc capacitor"))
out.append(sym("PWR_FLAG", "#FLG", "", [("1", "pwr", "power_out", "L", 0.0)],
               2.54, "", "Power flag", power=True))

open(f"{LIB}.kicad_sym", "w").write(
    '(kicad_symbol_lib (version 20241209) (generator "empire12-gen")'
    ' (generator_version "9.0")\n' + "\n".join(out) + "\n)\n")

ROOT = U()
items, refs = [], {}


def place(lib, ref, val, at, conns, nc=(), dnp=False):
    px, py = snap(at[0]), snap(at[1])
    coords = SYMS[lib]
    ys = [c[1] for c in coords.values()]
    r_off, v_off = snap(max(ys) + 5.08), snap(abs(min(ys)) + 5.08)
    items.append(f'''  (symbol (lib_id "{LIB}:{lib}") (at {px} {py} 0) (unit 1)
    (exclude_from_sim no) (in_bom {"no" if ref.startswith("#") else "yes"})
    (on_board yes) (dnp {"yes" if dnp else "no"}) (uuid "{U()}")
    (property "Reference" "{ref}" (at {px} {snap(py - r_off)} 0)
      (effects (font (size 1.27 1.27))))
    (property "Value" "{val}" (at {px} {snap(py + v_off)} 0)
      (effects (font (size 1.27 1.27))))
{"".join(f'    (pin "{n}" (uuid "{U()}"))' + chr(10) for n in coords)}    (instances (project "{PROJ}"
      (path "/{ROOT}" (reference "{ref}") (unit 1))))
  )''')
    for num, net in conns.items():
        cx, cy = coords[num]
        ax, ay = snap(px + cx), snap(py - cy)
        d = -2.54 if cx < 0 else 2.54
        ex = snap(ax + d)
        items.append(f'  (wire (pts (xy {ax} {ay}) (xy {ex} {ay}))'
                     f' (stroke (width 0) (type default)) (uuid "{U()}"))')
        just, rot = ("right", 180) if d < 0 else ("left", 0)
        items.append(f'''  (label "{net}" (at {ex} {ay} {rot})
    (effects (font (size 1.27 1.27)) (justify {just} bottom)) (uuid "{U()}"))''')
    for num in nc:
        cx, cy = coords[num]
        items.append(f'  (no_connect (at {snap(px + cx)} {snap(py - cy)})'
                     f' (uuid "{U()}"))')
    if not ref.startswith("#"):
        refs[ref] = val


# ===================== Pi header J1 (left) ================================
place("RPi_GPIO40", "J1", "RPi 40-pin GPIO", (63.5, 118.11), pins("J1"))

# ===================== E22 module U1 (right) ==============================
# ANT (pad 21) intentionally no-connect: the antenna leaves via the module's
# own IPEX connector and a pigtail. DIO2 unused (TXEN driven from GPIO13).
place("E22_900M30S", "U1", "E22-900M30S", (152.4, 118.11), pins("U1"),
      nc=NC["U1"])

# ===================== Decoupling ========================================
# C1 bulk: the 650 mA TX burst is a step load on a rail that arrives through
# a stacking header. C2/C3 are the "external ceramic filter capacitor" the
# datasheet asks for at each VCC pin.
#
# C1's value says 6.3 V because that is what is in stock, and 6.3 V on a 5 V
# rail is ~26 % headroom — right at the usual 80 % derating limit. BUY A 10 V
# OR 16 V PART. The footprint (D8.0 mm, P3.50 mm) is unchanged either way, so
# this is a purchasing decision, not a layout one.
# STACKED VERTICALLY, NOT IN A ROW, and that is load-bearing. place() draws a
# 2.54 mm stub off every pin and hangs the net label on its end. Side by side
# these three sat 5.08 mm pin-to-pin, so C1's right stub and C2's left stub met
# at exactly one point and WELDED GND TO +5V: the schematic netlist came out
# with no GND net at all and a 27-node "+5V" holding both plates of all three
# caps. It cost one ERC error that reads as a trivial two-PWR_FLAG complaint.
# Nothing on the PCB moved, because gen_pcb.py builds from netlist.py and never
# reads this sheet - so a dead short on the power rail stayed invisible in
# every board-side check. Keep adjacent pins > 5.08 mm apart, or stack.
place("CP", "C1", "1000uF 6.3V", (109.22, 152.4), {"1": "+5V", "2": "GND"})
place("C", "C2", "0.1uF", (109.22, 165.1), {"1": "+5V", "2": "GND"})
place("C", "C3", "0.1uF", (109.22, 177.8), {"1": "+5V", "2": "GND"})

# The Pi header is the only source on +5V/+3V3/GND and its pins are passive,
# so ERC needs flags or it reports "no power source".
place("PWR_FLAG", "#FLG_5", "PWR_FLAG", (109.22, 193.04), {"1": "+5V"})
place("PWR_FLAG", "#FLG_G", "PWR_FLAG", (129.54, 193.04), {"1": "GND"})
place("PWR_FLAG", "#FLG_3", "PWR_FLAG", (147.32, 193.04), {"1": "+3V3"})

TXT = []


def note(t, x, y, size=2.0):
    TXT.append(f'  (text "{t}" (at {snap(x)} {snap(y)} 0)'
               f' (effects (font (size {size} {size})) (justify left bottom))'
               f' (uuid "{U()}"))')


note("MeshGW Pi HAT - E22-900M30S carrier (rev A, 2026-08-12)", 20, 15.24, 3.0)
note("HAT mechanical geometry VERIFIED vs the Pi 3B+ 2026-08-12; U1's land", 20, 21.59, 2.0)
note("pattern is datasheet-derived and has NOT met a physical module. Bare", 20, 26.67, 2.0)
note("boards ordered anyway on that known risk - CHECK U1 FIT BEFORE SOLDERING.", 20, 31.75, 2.0)

# TWO COLUMNS, and below the components. The sheet is A3 (297 mm tall) and a
# single column of these notes ran off the bottom of the page — KiCad plots
# text outside the frame quite happily and says nothing about it.
NY, STEP = 203.0, 5.0
COLUMNS = [(20.0, [
    "POWER: E22 VCC = +5V (Pi header pins 2/4), NOT 3V3.",
    "  Datasheet: 2.5-5.5V range but '>=5.0V ensures output power',",
    "  650 mA instantaneous on a TX burst. The Pi 3V3 regulator must",
    "  not carry that. Logic level is 3.3V so SPI wires straight to",
    "  the Pi with no level shifting.",
    "",
    "RF: pad 21 (ANT stamp hole) is NO-CONNECT by design. The antenna",
    "  leaves through the module's own IPEX connector via an IPEX->SMA",
    "  bulkhead pigtail. Nothing on this 2-layer board is impedance-",
    "  controlled, and a bad RF trace passes every automated check.",
    "",
    "TXEN/RXEN are REQUIRED - the E22 has an RF switch. Leave them",
    "  unconnected and the PA transmits into a closed switch.",
    "",
    "NEVER power the module without an antenna: 1W into an open",
    "  circuit damages the PA.",
]), (200.0, [
    "PIN MAP (BCM) - generated from netlist.py, the ONE source:",
    "  NSS  GPIO5  (hdr 29)   BUSY GPIO27 (hdr 13)",
    "  SCK  GPIO11 (hdr 23)   DIO1 GPIO17 (hdr 11)",
    "  MOSI GPIO10 (hdr 19)   NRST GPIO22 (hdr 15)",
    "  MISO GPIO9  (hdr 21)   TXEN GPIO13 (hdr 33)",
    "                         RXEN GPIO6  (hdr 31)",
    "  This sheet and the PCB are both generated from it, so they",
    "  cannot drift. config/meshtasticd/config.yaml is NOT generated -",
    "  re-pin here and you must hand-edit it or the radio won't start.",
    "  Diverges from MeshAdv-Pi-Hat deliberately; netlist.py says why.",
    "",
    "GEOMETRY: 65 x 56.0 mm, R3 corners, notched for the Pi 3B+ PoE",
    "  header J14 (those pins can carry ~48-57V on a PoE switch).",
    "  Verified vs the official HAT spec 2026-08-12; check_geometry.py",
    "  asserts 27 of those facts against the ROUTED board every run.",
])]
# 284, not A3's 297: the usable area ends at the drawing FRAME's inner edge,
# and KiCad plots text past it without complaint. Assert against what a reader
# can actually see.
FRAME_BOTTOM = 284.0
for nx, lines in COLUMNS:
    assert NY + len(lines) * STEP < FRAME_BOTTOM, \
        f"notes column at x={nx} runs past the A3 frame"
    for i, line in enumerate(lines):
        if line:
            note(line, nx, NY + i * STEP, 1.7)

sch = f'''(kicad_sch (version 20250114) (generator "empire12-gen") (generator_version "9.0")
  (uuid "{ROOT}")
  (paper "A3")
  (title_block (title "MeshGW Pi HAT - E22-900M30S carrier") (date "2026-08-12")
    (rev "A") (company "Empire12"))
  (lib_symbols)
{chr(10).join(items)}
{chr(10).join(TXT)}
  (sheet_instances (path "/" (page "1")))
)
'''

lib = open(f"{LIB}.kicad_sym").read()
blocks, i = [], 0
while True:
    m = re.search(r'\n  \(symbol "([^"]+)"', lib[i:])
    if not m:
        break
    start, name = i + m.start() + 1, m.group(1)
    d, j = 0, start
    while True:
        if lib[j] == '(':
            d += 1
        elif lib[j] == ')':
            d -= 1
            if d == 0:
                break
        j += 1
    blocks.append(lib[start:j + 1].replace(
        f'(symbol "{name}"', f'(symbol "{LIB}:{name}"', 1))
    i = j + 1
sch = sch.replace("  (lib_symbols)", "  (lib_symbols\n" + "\n".join(blocks) + "\n  )")
open(f"{PROJ}.kicad_sch", "w").write(sch)

open("sym-lib-table", "w").write(
    '(sym_lib_table\n  (version 7)\n  (lib (name "mgw")(type "KiCad")'
    '(uri "${KIPRJMOD}/mgw.kicad_sym")(options "")(descr "MeshGW symbols"))\n)\n')
open("fp-lib-table", "w").write(
    '(fp_lib_table\n  (version 7)\n  (lib (name "mgw")(type "KiCad")'
    '(uri "${KIPRJMOD}/lib.pretty")(options "")(descr "MeshGW footprints"))\n)\n')
open(f"{PROJ}.kicad_pro", "w").write(json.dumps({
    "board": {"design_settings": {}},
    "libraries": {"pinned_footprint_libs": [], "pinned_symbol_libs": []},
    "meta": {"filename": f"{PROJ}.kicad_pro", "version": 3},
    "sheets": [[ROOT, "Root"]]}, indent=2) + "\n")

print(f"symbols: {len(out)}   components: {len(refs)}")
for r, v in sorted(refs.items()):
    print(f"  {r:6} {v}")

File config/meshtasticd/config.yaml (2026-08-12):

# meshtasticd — Mesh Internet Gateway (meshgw)
# Install to /etc/meshtasticd/config.yaml
#
# This file describes HARDWARE ONLY (which radio, on which pins). Region,
# channels, MQTT and map reporting are *device* settings held in the node's
# own config — see scripts/provision-meshgw.sh, which is the authority for
# those and encodes the privacy boundary.
#
# Pin numbers are BCM GPIO. The authority for this map is
# hardware/meshgw-hat/netlist.py — it is what the copper actually does, and
# this file only tells meshtasticd about it. If they disagree, the radio does
# not come up. The starting point was the open-source MeshAdv-Pi-Hat reference
# design (https://github.com/chrismyers2000/MeshAdv-Pi-Hat) but this HAT
# DIVERGES from it: every control line was moved onto an odd-numbered header
# pin (the Pi's inner row) because the reference map could not be routed on a
# board this size, and because the resulting boot-time pull states are safer —
# GPIO5 idles the chip DESELECTED, where the reference's GPIO21 asserted
# chip-select on every boot. netlist.py has the full reasoning.
#
# UNVERIFIED against real hardware — nothing has been built yet.

Lora:
  Module: sx1262
  # SPI0. Note CS is a plain GPIO (software chip-select), NOT CE0/GPIO8.
  spidev: spidev0.0
  CS: 5            # header pin 29
  IRQ: 17          # header pin 11 — E22 DIO1
  Busy: 27         # header pin 13
  Reset: 22        # header pin 15
  # E22-900M30S has a PA and an RF switch — TXen/RXen are REQUIRED. Omit them
  # and the module transmits into a closed switch: no range, possible damage.
  TXen: 13         # header pin 33
  RXen: 6          # header pin 31
  # The E22's SX1262 clocks from a TCXO fed off DIO3. Without this the radio
  # either fails to start or drifts off frequency.
  DIO3_TCXO_VOLTAGE: true

  # 30 dBm (1 W) is the module's rated ceiling. Leave headroom rather than
  # pinning the maximum until the supply rail is proven under TX burst —
  # brownout during TX looks exactly like a bad antenna.
  # Set the actual value as a device setting (lora.tx_power), not here.

Logging:
  LogLevel: info
  # Journald picks this up; the ops Wazuh agent ships it (see docs/).

Webserver:
  # Local diagnostics only. Do NOT expose this off-box — meshtasticd's
  # webserver is unauthenticated, the same reason the HA TCP-proxy was left
  # off (see meshtastic-lora-ha-node memory).
  Port: 9443
  RootPath: /usr/share/meshtasticd/web

General:
  MaxNodes: 200
  MaxMessageQueue: 100

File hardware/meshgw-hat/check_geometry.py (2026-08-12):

#!/usr/bin/env python3
"""Assert the MeshGW HAT's mechanical facts against the ROUTED board.

    ./check_geometry.py meshgw-hat-routed.kicad_pcb

Why this exists: on this toolchain a board can pass `kicad-cli pcb drc` with
0 violations and 0 unconnected and still be scrap. DRC has no opinion about
whether the header sits where a Raspberry Pi's header actually is, whether the
board is the size the HAT spec says, whether the ground pour really filled, or
whether a track is wide enough for the current it carries. The previous
revision of this board passed DRC cleanly with its two header rows swapped —
every SPI signal would have landed on its neighbouring pin.

Every number here comes from the specification, not from whatever the
generator happened to emit; the sources are cited in gen_pcb.py's docstring.
If a check fails the board is wrong. If a check needs changing, the
specification changed.

The board is parsed as s-expressions, not with regexes: pcbnew rewrites this
file in its own canonical multi-line form when fill_zones.py saves it, so the
one-line shapes gen_pcb.py emits are not what ends up on disk.
"""
import math
import re
import sys

BX, BY = 100.0, 60.0           # board origin on the KiCad page
BW, BH = 65.0, 56.0
CORNER_R = 3.0
MOUNT = [(3.5, 3.5), (61.5, 3.5), (3.5, 52.5), (61.5, 52.5)]
MOUNT_LAND = 6.2
# Pi 3B+ PoE header J14 body, measured off the official mechanical drawing.
J14 = (59.05, 7.38, 64.02, 11.92)
MIN_5V_WIDTH = 0.4             # see route.sh for the current-carrying sum

fails, checks = [], 0


def parse(text):
    toks = re.findall(r'"(?:[^"\\]|\\.)*"|[()]|[^\s()]+', text)
    stack, cur = [], []
    for t in toks:
        if t == '(':
            stack.append(cur)
            cur = []
        elif t == ')':
            parent = stack.pop()
            parent.append(cur)
            cur = parent
        else:
            cur.append(t[1:-1] if t.startswith('"') else t)
    return cur[0]


def kids(node, tag):
    return [c for c in node if isinstance(c, list) and c and c[0] == tag]


def kid(node, tag):
    k = kids(node, tag)
    return k[0] if k else None


def walk(node, tag):
    """Every descendant with this tag, at any depth."""
    out = []
    if isinstance(node, list):
        if node and node[0] == tag:
            out.append(node)
        for c in node:
            if isinstance(c, list):
                out += walk(c, tag)
    return out


def xy(node, tag):
    n = kid(node, tag)
    return (float(n[1]), float(n[2])) if n else None


def ok(cond, msg):
    global checks
    checks += 1
    if not cond:
        fails.append(msg)


def local(p):
    return (p[0] - BX, p[1] - BY)


def main(path):
    root = parse(open(path).read())

    # ---------------------------------------------------------- board outline
    edge = [(xy(l, "start"), xy(l, "end")) for l in kids(root, "gr_line")
            if (kid(l, "layer") or [None, None])[1] == "Edge.Cuts"]
    ok(bool(edge), "no Edge.Cuts outline at all")
    if edge:
        pts = [local(p) for seg in edge for p in seg]
        w = max(p[0] for p in pts) - min(p[0] for p in pts)
        h = max(p[1] for p in pts) - min(p[1] for p in pts)
        ok(abs(w - BW) < 0.01, f"board width {w:.3f}, expected {BW} (HAT spec)")
        ok(abs(h - BH) < 0.01,
           f"board height {h:.3f}, expected {BH} — 56.0 is the through-hole "
           f"header figure, 56.5 is only for an SMT header")
        # Radiused corners are mandatory; with them the square corner point
        # itself never appears on the outline.
        for cx, cy in [(0, 0), (BW, 0), (0, BH), (BW, BH)]:
            ok(not any(abs(p[0] - cx) < 0.01 and abs(p[1] - cy) < 0.01
                       for p in pts),
               f"corner ({cx},{cy}) is square; the HAT spec requires R{CORNER_R}")
        # The PoE notch must actually be cut, not merely kept clear of copper.
        ok(sum(1 for a, b in edge
               if all(local(p)[0] > 55 and local(p)[1] < 16 for p in (a, b))
               ) >= 3, "no PoE notch in Edge.Cuts near the top-right corner")

    # ------------------------------------------------------- J1 header pads
    # Pin 1 at (8.37, 4.77); ODD pins on the inner row, EVEN pins on the outer
    # row nearest the board edge — which is where the Pi puts 5V (pins 2/4).
    j1 = [f for f in kids(root, "footprint")
          if "RPi_GPIO40_Horizontal" in f[1]]
    ok(len(j1) == 1, "J1 (40-pin header) footprint not found")
    if j1:
        origin = xy(j1[0], "at")
        pads = {int(p[1]): xy(p, "at") for p in kids(j1[0], "pad")
                if p[1].isdigit()}
        ok(len(pads) == 40, f"J1 has {len(pads)} pads, expected 40 "
                            f"(HAT spec: board must have a full 40W connector)")
        bad = []
        for pin, p in pads.items():
            lx, ly = local((origin[0] + p[0], origin[1] + p[1]))
            wx = 8.37 + ((pin - 1) // 2) * 2.54
            wy = 4.77 if pin % 2 else 2.23
            if abs(lx - wx) > 0.01 or abs(ly - wy) > 0.01:
                bad.append(f"pin {pin} at ({lx:.2f},{ly:.2f}) want "
                           f"({wx:.2f},{wy:.2f})")
        ok(not bad, "J1 pads are not where the Pi's header is, so the board "
                    "will not seat correctly: " + "; ".join(bad[:4]))

    # --------------------------------------------------------- mounting holes
    holes = [xy(f, "at") for f in kids(root, "footprint")
             if f[1].startswith("MountingHole")]
    ok(len(holes) == 4, f"{len(holes)} mounting holes, expected 4")
    for mx, my in MOUNT:
        ok(any(abs(h[0] - (BX + mx)) < 0.01 and abs(h[1] - (BY + my)) < 0.01
               for h in holes), f"no mounting hole at ({mx},{my})")
    drills = [float(d[1]) for f in kids(root, "footprint")
              if f[1].startswith("MountingHole") for d in walk(f, "drill")]
    ok(drills and all(abs(d - 2.75) < 0.01 for d in drills),
       f"mounting hole drills are {sorted(set(drills))}, spec says 2.75 mm")

    # ------------------------------------------------------------ copper map
    segs = []
    for sg in kids(root, "segment"):
        net = kid(sg, "net")
        segs.append((xy(sg, "start"), xy(sg, "end"),
                     float(kid(sg, "width")[1]),
                     int(net[1]) if net else 0))
    ok(bool(segs), "no routed tracks in this file — did the SES import run?")
    vias = [xy(v, "at") for v in kids(root, "via")]

    # Zone copper: the fill is what actually exists on the board, and
    # ZONE.IsFilled() lies, so count real filled_polygon vertices.
    fillpts = [(float(p[1]), float(p[2]))
               for fp in walk(root, "filled_polygon")
               for p in walk(fp, "xy")]
    ok(len(fillpts) > 20,
       f"GND pour has {len(fillpts)} filled vertices — the pour did not fill, "
       f"and an unfilled zone contributes no copper and no connectivity")
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

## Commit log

2026-08-11 meshgw: Pi + E22 LoRa internet gateway — design, HAT, enclosure
    Bridges the Empire12 / Techtaria LoRa mesh to the internet over MQTT and
    publishes E12-owned nodes to the public Meshtastic map directories.
    Separate hardware rather than adding MQTT to the existing Heltec V4 gateway:
    that radio sits on the OOB control path (D048) and its ESP32 WiFi stack hangs
    often enough that it was down mid-design. ESP32 + Ethernet was ruled out —
    firmware PR #9586 is closed and unmerged, so it would mean a fork on the
    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
    [meshgw-case.scad, meshgw-hat-routed.kicad_pcb, meshgw-hat.kicad_pcb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]
2026-08-11 meshgw: flag C1 voltage margin, add enclosure Makefile
    C1 is specced 1000uF 6.3V because that is what is in stock. On the E22's 5V
    rail that is ~26% headroom, right at the usual 80% derating limit. Same
    footprint at 10V or 16V, so it is a purchasing decision — recorded in gen.py
    next to the part and in the pre-order checklist.
    [meshgw-hat-routed.kicad_pcb, meshgw-hat.kicad_pcb, meshgw-hat.kicad_sch]
2026-08-12 meshgw HAT: verify mechanical geometry vs Pi 3B+, unify netlist, fix schematic short
    The HAT geometry was unverified against the official Raspberry Pi HAT spec,
    as route.sh itself warned. Verified against three independent sources (the
    HAT mechanical PDF, the Pi 3B+ drawing, and KiCad's own HAT template plus its
    Pi Zero socketed footprint). It was wrong six ways while passing DRC with
    0 violations and 0 unconnected:
    - header rows swapped: every SPI signal onto its neighbour's pin
    - header origin (7.0, 2.5) instead of (8.37, 4.77): would not seat at all
    - 56.5 mm tall: that is the SMT-header figure, through-hole needs 56.0
    - square corners against a spec mandating R3
    - pour flooded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
    [meshgw-hat-routed.kicad_pcb, meshgw-hat.kicad_pcb, meshgw-hat.kicad_sch]
2026-08-12 meshgw HAT: regenerated artifacts after notes-column fit
    [meshgw-hat-routed.kicad_pcb, meshgw-hat.kicad_pcb, meshgw-hat.kicad_sch]
2026-08-12 meshgw HAT: document the E22 land-pattern deviation and its verification state
    The 2.0 mm land against the datasheet's 0.80 mm castellation is deliberate --
    1.0 mm outside the body for a solder fillet -- and was not recorded as such,
    so a future reader could 'correct' it back and lose the fillet.
    Internal consistency of the footprint re-checked against its own cited
    datasheet figures: pad count, first-pad offset, pitch, both irregular gaps
    and the pin ring direction all agree. What remains unverifiable without the
    physical module is whether those cited figures are themselves right. Module
    ordered 2026-08-12, not yet received.
    [meshgw-hat-routed.kicad_pcb, meshgw-hat.kicad_pcb, meshgw-hat.kicad_sch]
2026-08-12 meshgw HAT: clear rev A to order, build the fab package
    Don's call 2026-08-12: batch the bare board into the shared JLCPCB checkout
    with OSL, FD2, pool and Sentinel. Boards are ~$2 against $6-25 shipping, so
    holding it back would pay that shipping charge again later with certainty.
    U1's land pattern has still never met a physical module -- the E22 was ordered
    the same day and is weeks out. fab_gate.py therefore keeps GEOMETRY_VERIFIED
    False and carries a SEPARATE GEOMETRY_OVERRIDE string naming who decided, when
    and why. Flipping the flag would have been one character and would have
    destroyed the distinction between 'we checked' and 'we accepted the risk',
    which is exactly what a reader six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
    [meshgw-hat-fab-B_Cu.gbl, meshgw-hat-fab-B_Mask.gbs, meshgw-hat-fab-B_Silkscreen.gbo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]
2026-08-12 meshgw: record projected cost now the BOM is fully priced
    PartsBin project 18 audits at 0 gaps; projected $46.49 -> $81.81.
    The E22's price came from the ORDER, not the web: PartsBin's estimator
    returned $7.19 (LCSC) but AliExpress order 1773 totals $17.10 on a
    single-item order, which is what was actually paid. The gap is probably
    bundled shipping and is worth checking before buying a second module.
    $35 of the total is the Raspberry Pi -- check the shelf first, a spare
    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
2026-08-14 Add generated text schematic (PartsBin SOP)
    The project SOP now requires a plain-text schematic alongside the drafted
    one: a netlist plus polarity notes that greps, diffs between revisions, and
    stays readable without opening KiCad.
    Generated by /opt/empire12-ops/scripts/kicad_text_schematic.py from
    kicad-cli sch export netlist — regenerate rather than hand-editing. Text
    below the HAND NOTES marker survives regeneration.
2026-09-09 HAT geometry VERIFIED on hardware; clear the fab override; mark deployed
    The E22-900M30S was soldered to a rev A board and meshtasticd reported
    `sx1262 init success` on first start, with the node then transmitting on the
    mesh. The land pattern is correct and the boards fabbed on the recorded
    GEOMETRY_OVERRIDE are not scrap.
    GEOMETRY_VERIFIED is now True and GEOMETRY_OVERRIDE is cleared, which is exactly
    what the README said to do once the module met the board. The override existed
    so "we decided to risk it" could never be mistaken for "verified"; the risk is
    now resolved by observation, so the flag is the honest record.
    README: status moved from "bare boards cleared to order, nothing fabbe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
    [fab_gate.py]
